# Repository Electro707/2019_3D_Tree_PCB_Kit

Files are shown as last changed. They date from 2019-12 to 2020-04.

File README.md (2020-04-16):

# 2019_3D_Tree_PCB_Kit
A soldering kit of a "3D" Christmas Tree

This repository is archived, as it's a one-time design.
Now files are hosted on Google Drive.

Link to website, in which the Google Drive link can be found:
[Link](https://electro707.com/documentation/PCB/2019_3DChristmasTree/index.php)

I may create a new general reposity for the kit that will be updated as time goes on 
(there also won't be any of the University of New Haven logos on that one).

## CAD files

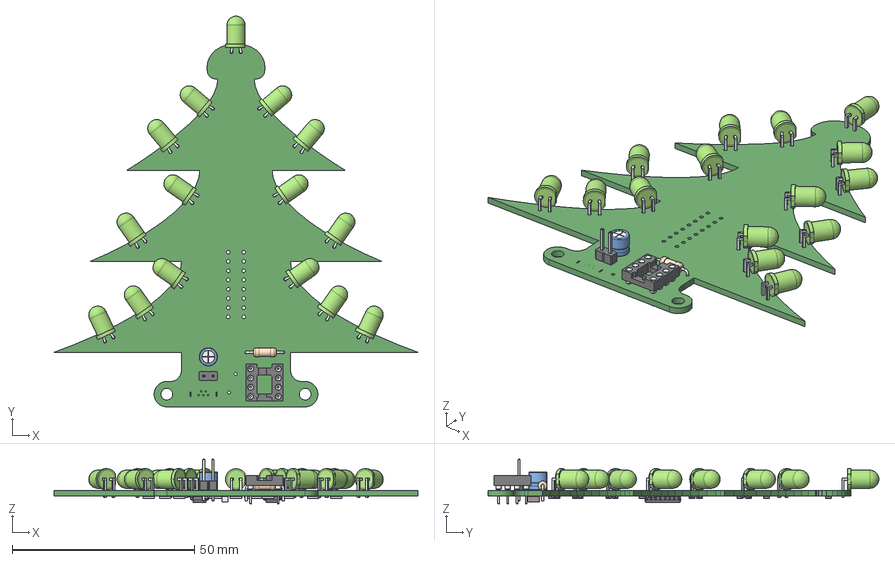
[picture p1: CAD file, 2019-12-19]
CAD - Inventor/Main Tree.step
100.0 x 107.4 x 12.3 mm

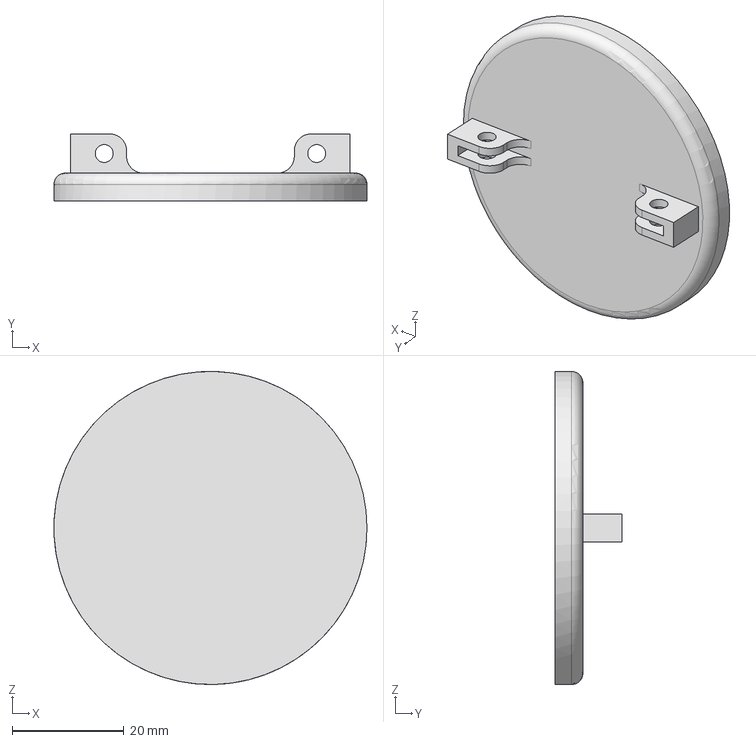
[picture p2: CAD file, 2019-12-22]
Base STEP and STL/Base.stp
56.0 x 12.0 x 56.0 mm

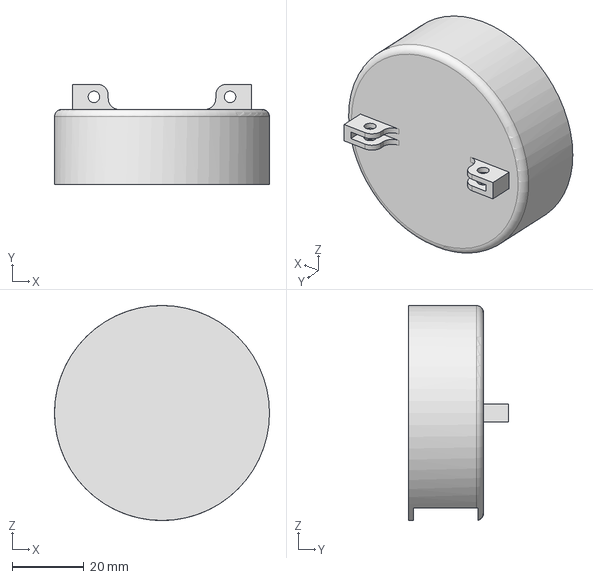
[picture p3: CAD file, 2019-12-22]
Base STEP and STL/Base with 9V Batt.stp
60.0 x 28.0 x 60.0 mm

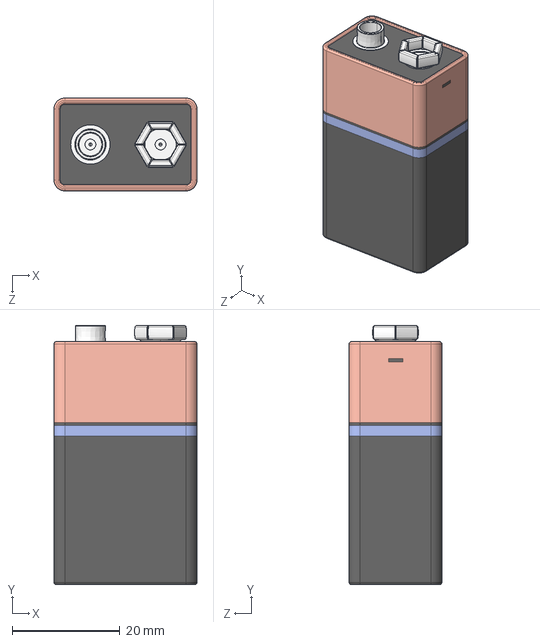
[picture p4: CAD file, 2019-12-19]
CAD - Inventor/9V Battery.STEP
26.5 x 48.0 x 17.2 mm

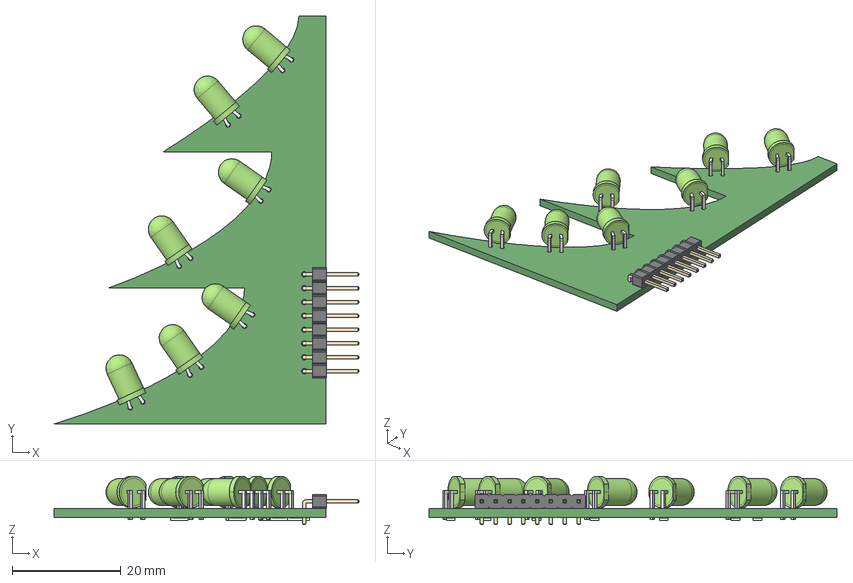
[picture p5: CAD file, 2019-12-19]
CAD - Inventor/Aux Tree.step
56.0 x 75.0 x 8.90 mm

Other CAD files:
CAD - Inventor/Drawings.dwg
Base STEP and STL/Base with 9V Batt.stl
Base STEP and STL/Base.stl
CAD - Inventor/Assembly - Aux Tree.iam
CAD - Inventor/Assembly - Main Tree.iam
CAD - Inventor/Assembly - Whole - 9V base.iam
CAD - Inventor/Assembly - Whole.iam
CAD - Inventor/Assembly - Whole.ipn
CAD - Inventor/Base with 9V Batt.ipt
CAD - Inventor/Base.ipt
CAD - Inventor/DIP-8_W7.62mm.ipt
CAD - Inventor/OldVersions/Assembly - Whole.0033.ipn
CAD - Inventor/OldVersions/Assembly - Whole.0034.iam

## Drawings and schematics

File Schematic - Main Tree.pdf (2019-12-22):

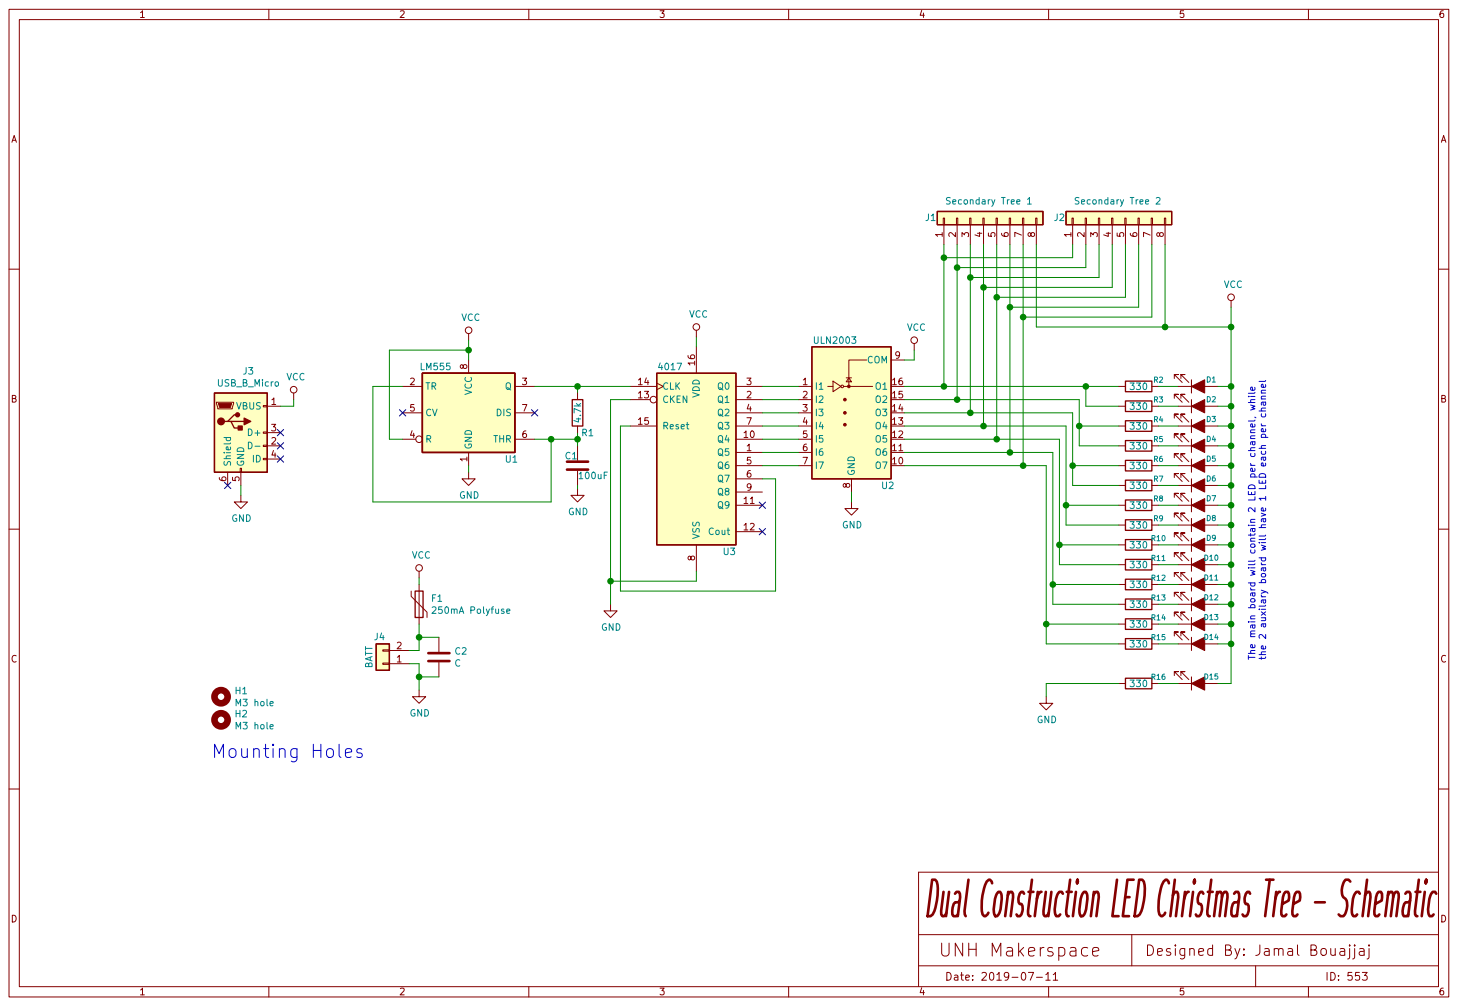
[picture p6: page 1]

H1M3 hole H2M3 hole Mounting Holes

Dual Construction LED Christmas Tree - Schematic

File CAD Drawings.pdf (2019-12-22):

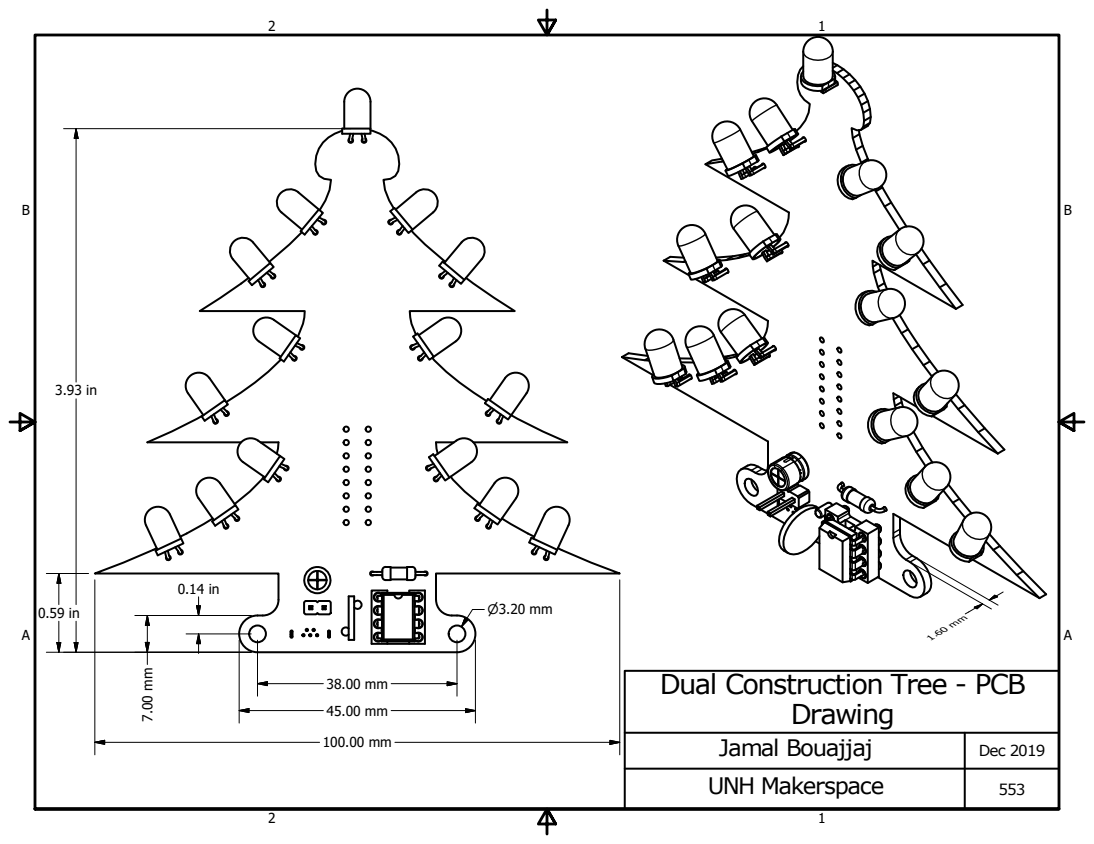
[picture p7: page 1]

Dual Construction Tree - PCB

Jamal Bouajjaj | Dec 2019
UNH Makerspace | 553

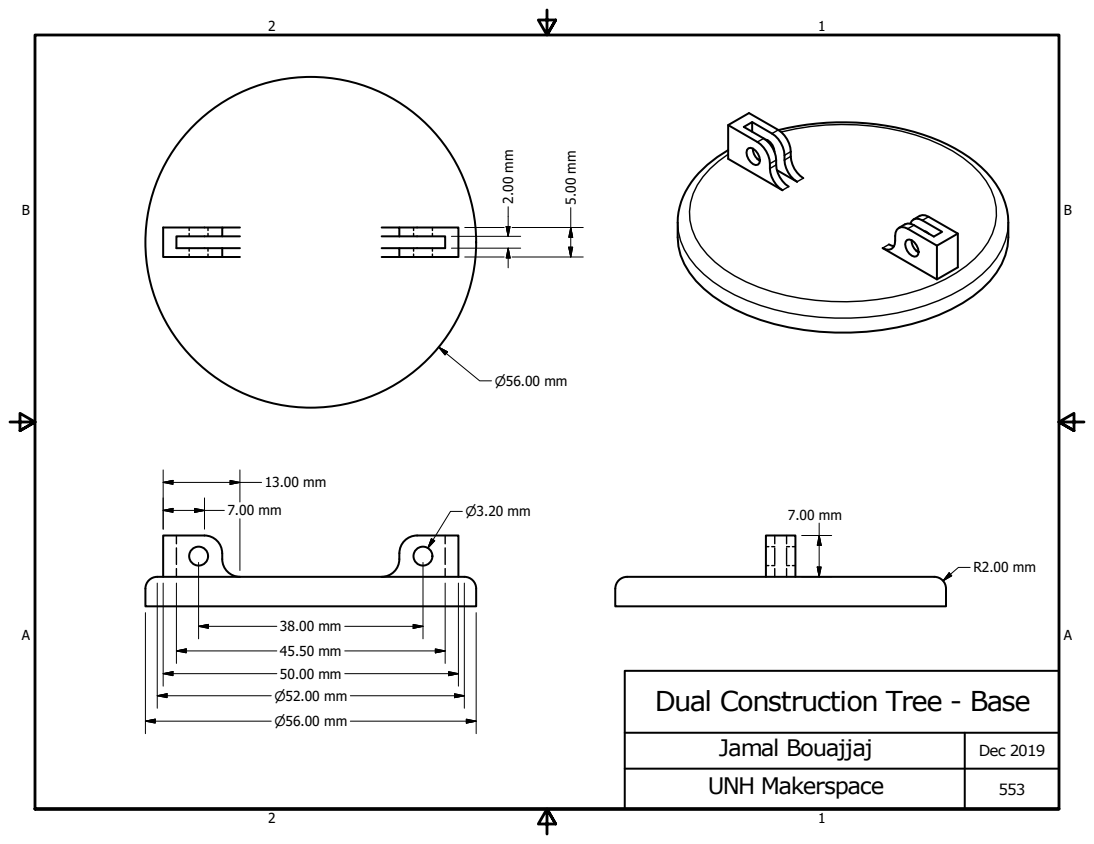
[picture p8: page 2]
Jamal Bouajjaj; Dec 2019

Dual Construction Tree - Base

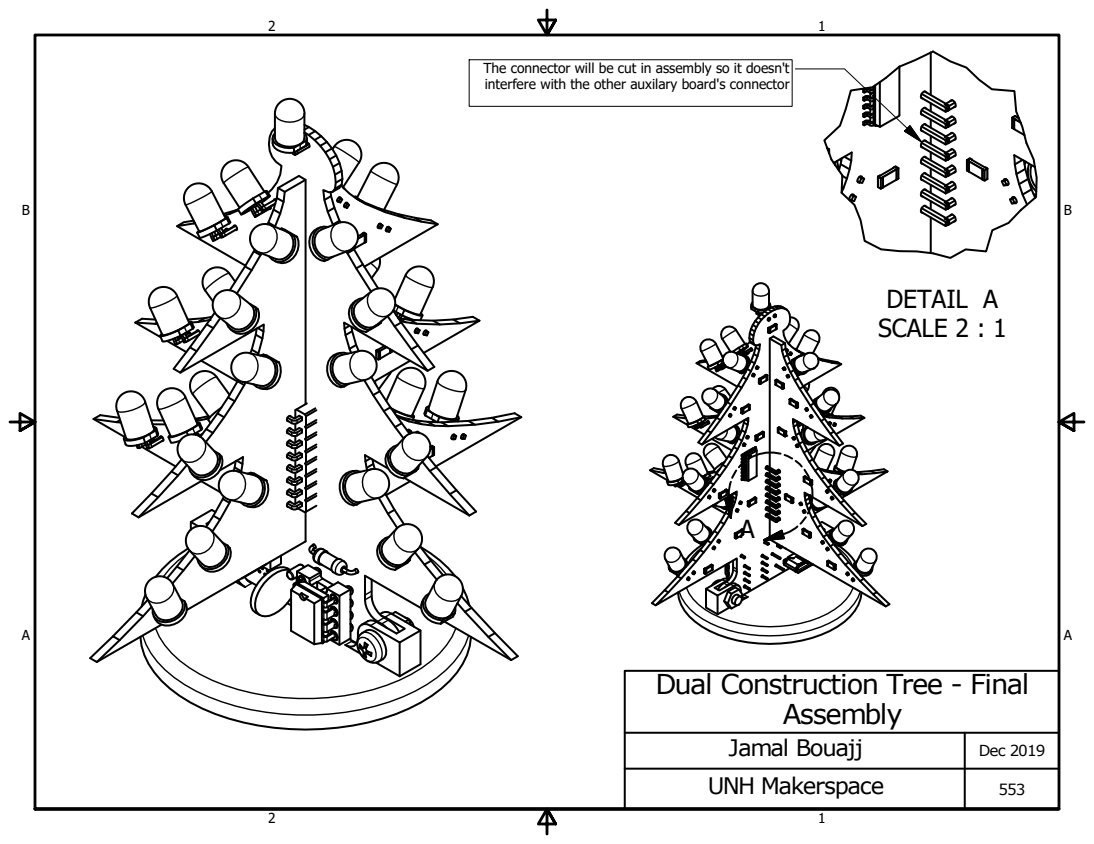
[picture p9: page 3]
DETAIL A SCALE 2 : 1; Jamal Bouajj; Dec 2019

The connector will be cut in assembly so it doesn't
interfere with the other auxilary board's connector

Dual Construction Tree - Final

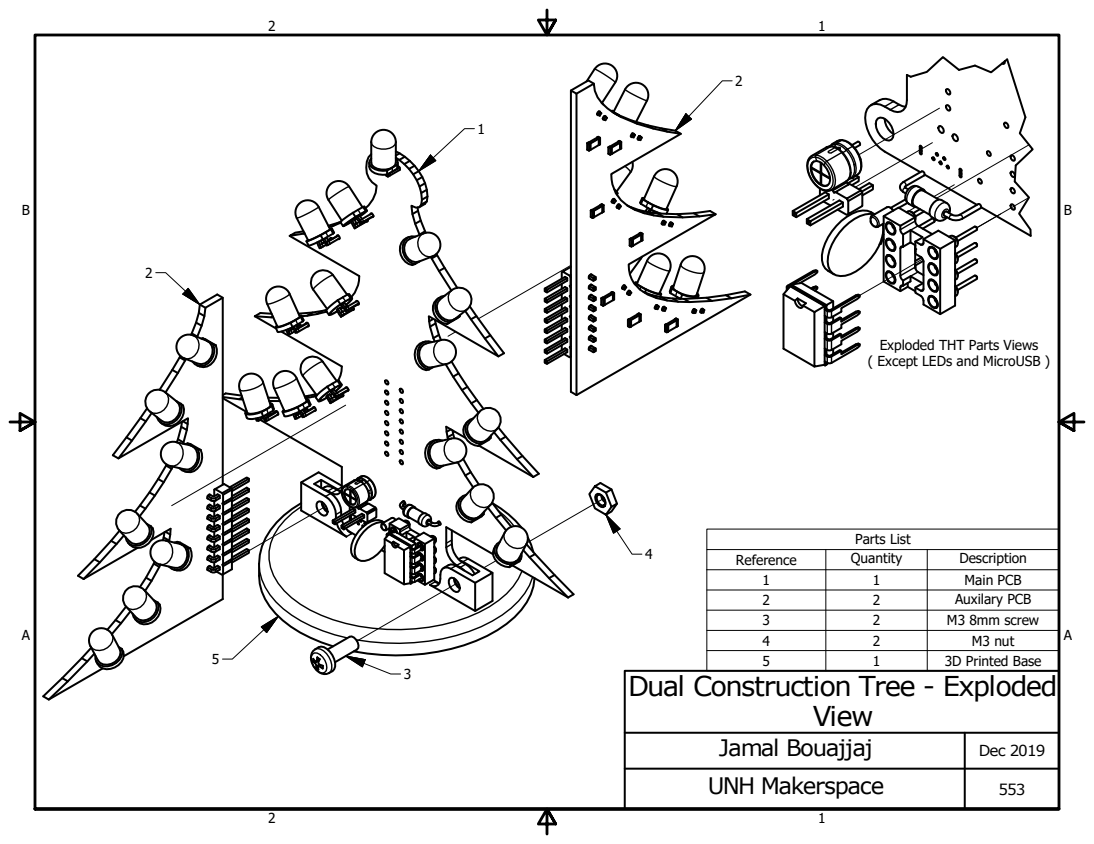
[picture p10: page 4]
Jamal Bouajjaj; Dec 2019; Parts List

Exploded THT Parts Views
( Except LEDs and MicroUSB )

Reference | Quantity | Description
1 | 1 | Main PCB
2 | 2 | Auxilary PCB
3 | 2 | M3 8mm screw
4 | 2 | M3 nut
5 | 1 | 3D Printed Base

Dual Construction Tree - Exploded

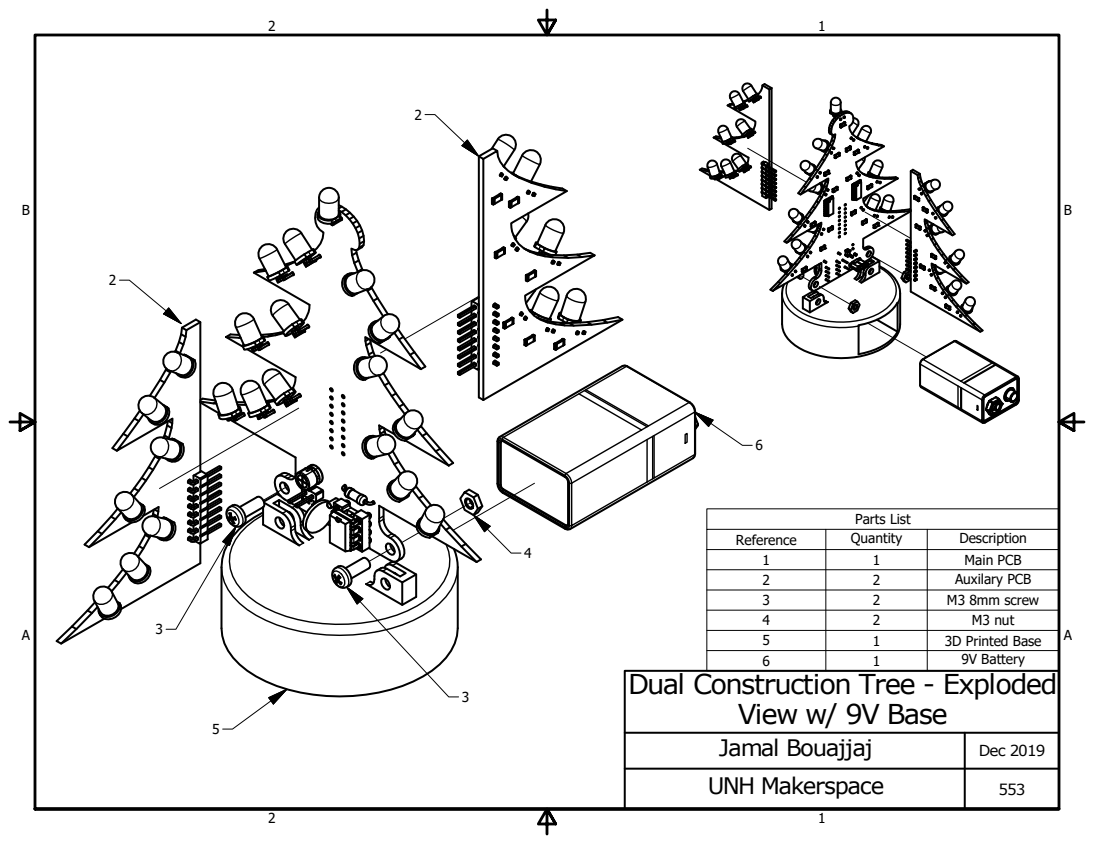
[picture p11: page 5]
View w/ 9V Base; Jamal Bouajjaj; Dec 2019; Parts List

Reference | Quantity | Description
1 | 1 | Main PCB
2 | 2 | Auxilary PCB
3 | 2 | M3 8mm screw
4 | 2 | M3 nut
5 | 1 | 3D Printed Base
6 | 1 | 9V Battery

Dual Construction Tree - Exploded

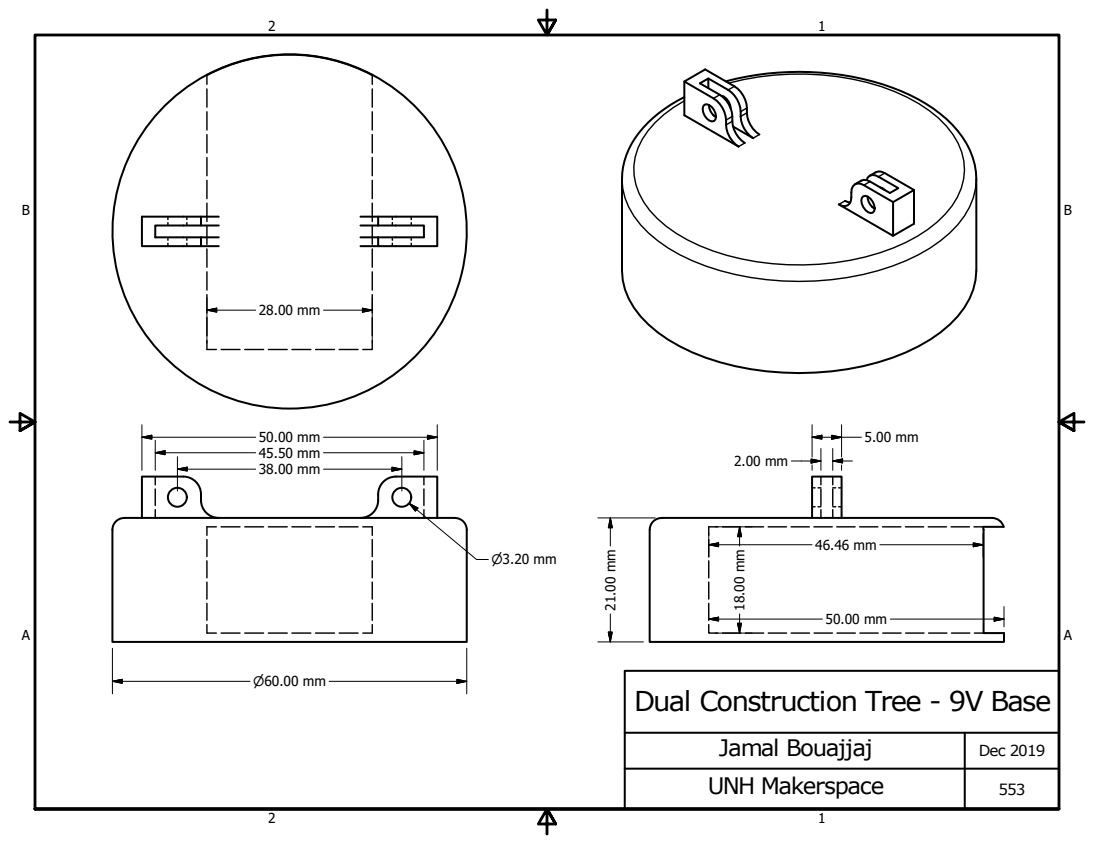
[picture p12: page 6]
Jamal Bouajjaj; Dec 2019

Dual Construction Tree - 9V Base

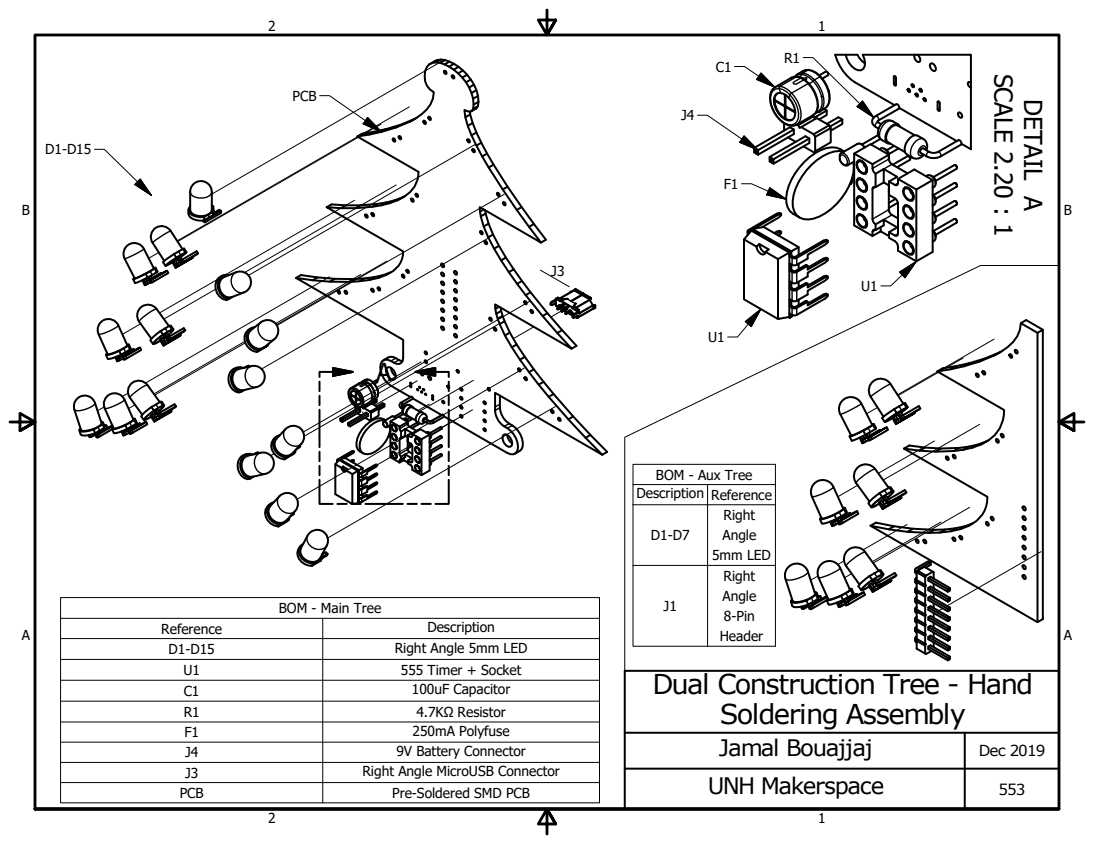
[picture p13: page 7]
Jamal Bouajjaj; Dec 2019

BOM - Aux Tree

Description | Reference
D1-D7 | Right Angle 5mm LED

J1 | Right Angle 8-Pin Header

BOM - Main Tree

Reference | Description
D1-D15 | Right Angle 5mm LED
U1 | 555 Timer + Socket
C1 | 100uF Capacitor
R1 | 4.7K Resistor
F1 | 250mA Polyfuse
J4 | 9V Battery Connector
J3 | Right Angle MicroUSB Connector
PCB | Pre-Soldered SMD PCB

Dual Construction Tree - Hand
Soldering Assembly

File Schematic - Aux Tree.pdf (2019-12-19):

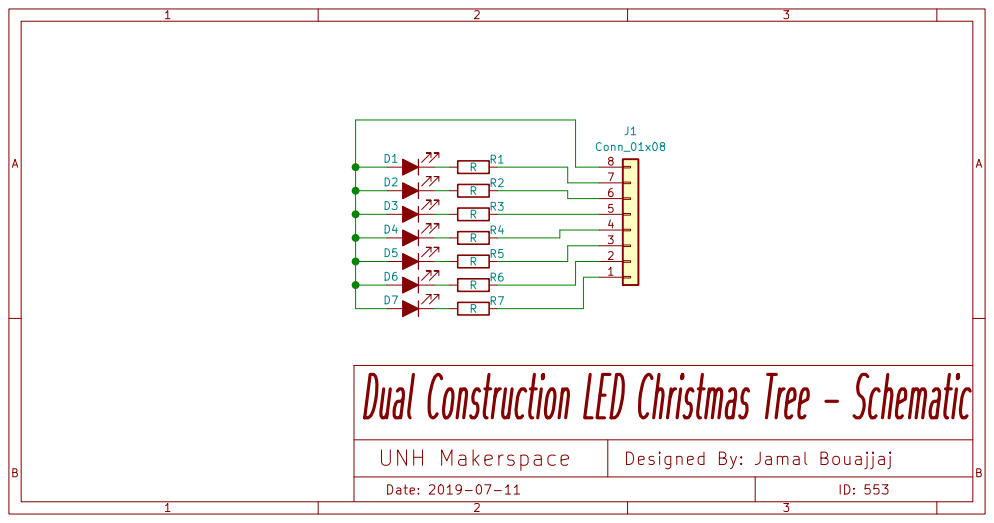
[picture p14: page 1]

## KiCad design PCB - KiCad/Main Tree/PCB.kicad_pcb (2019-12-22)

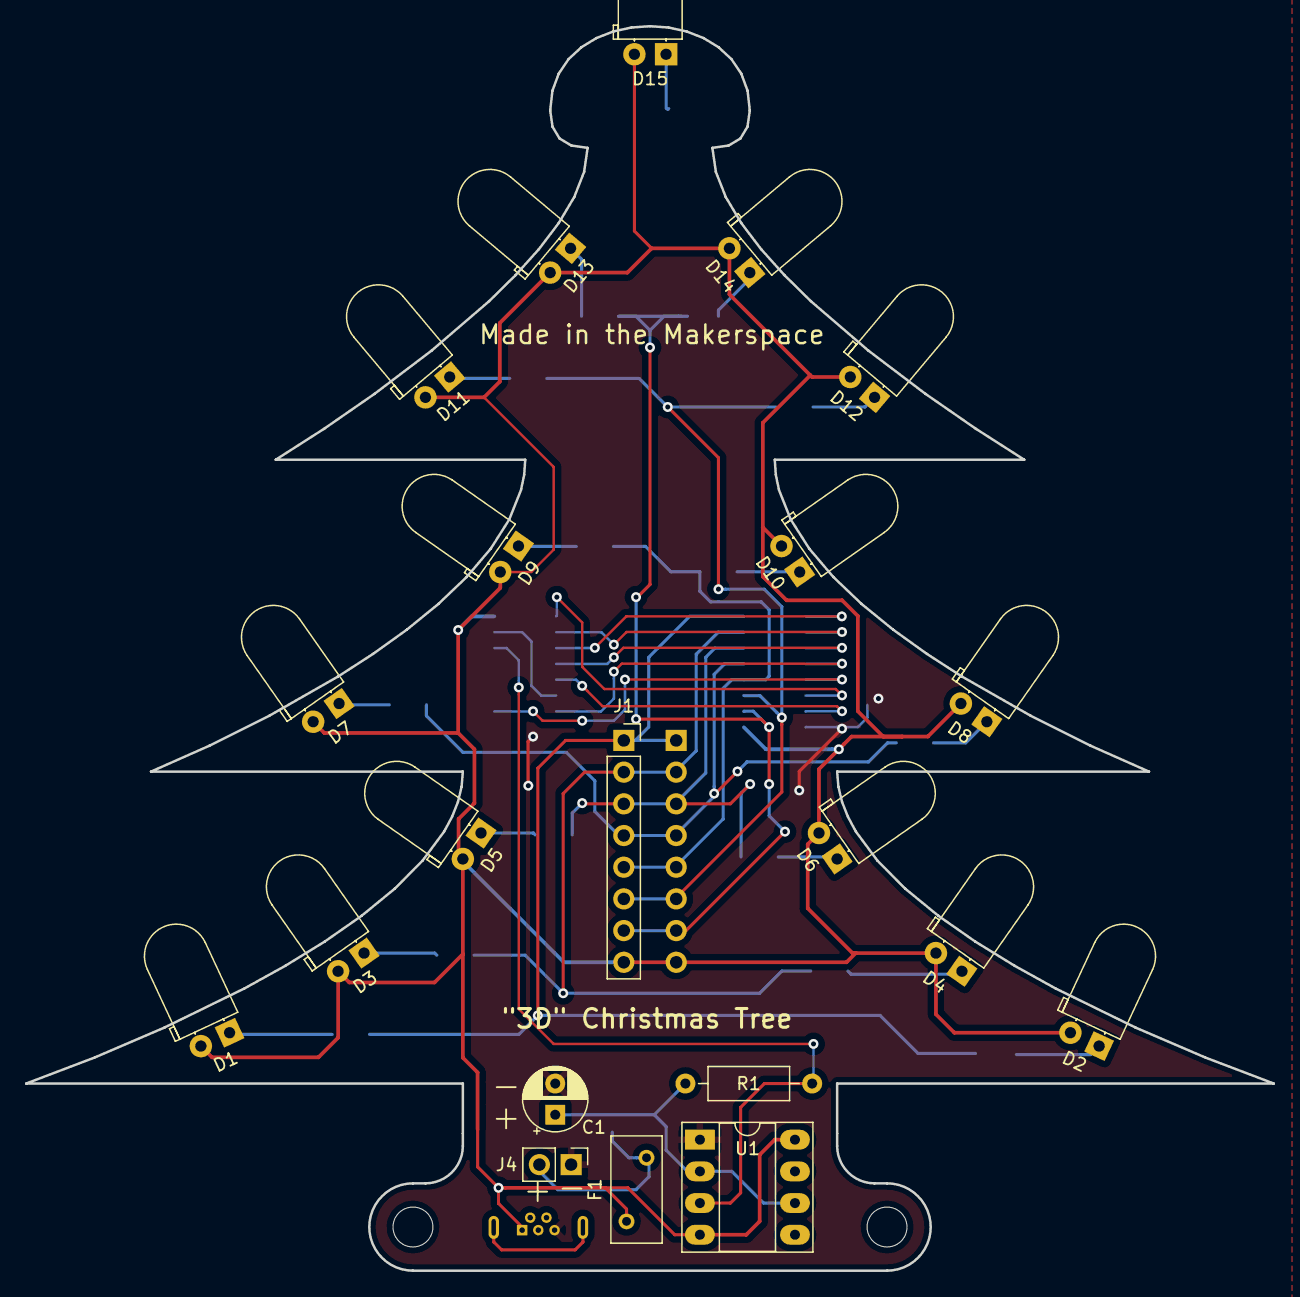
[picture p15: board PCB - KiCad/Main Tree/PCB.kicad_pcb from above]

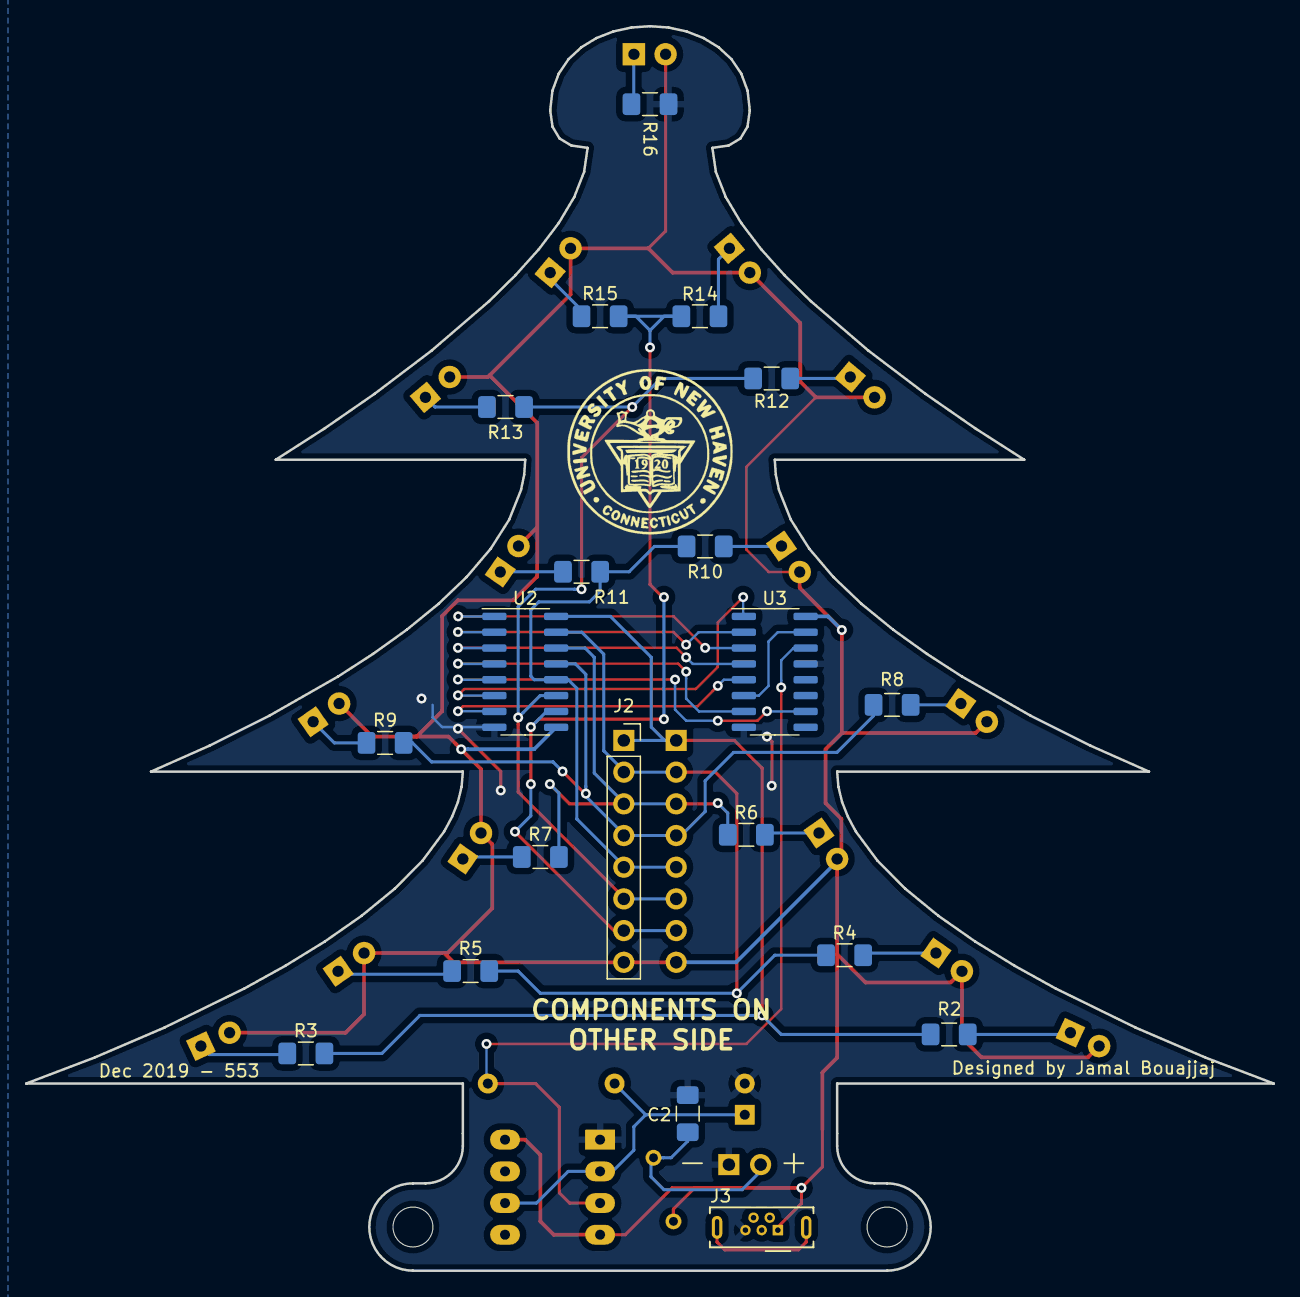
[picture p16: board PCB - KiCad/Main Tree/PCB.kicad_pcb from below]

Board: 2 copper layers, 100.0 x 99.8 mm, 43 parts (20 on the bottom side), 35 nets.

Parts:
C1: C; CP_Radial_D5.0mm_P2.50mm
C2: C; C_1206_3216Metric_Pad1.42x1.75mm_HandSolder
D1, D2, D3, D4, D5, D6, D7, D8, D9, D10, D11, D12, D13, D14, D15: LED_ALT; LED_D5.0mm_Horizontal_O1.27mm_Z3.0mm
F1: Polyfuse; Fuse_BelFuse_0ZRE0005FF_L8.3mm_W3.8mm
H1, H2: M3 hole; MountingHole_3.2mm_M3_DIN965
J1: Secondary Tree 1; PinSocket_1x08_P2.54mm_Vertical
J2: Secondary Tree 2; PinSocket_1x08_P2.54mm_Vertical
J3: USB_B_Micro; USB_Micro-B_Wuerth_614105150721_Vertical
J4: BATT; PinHeader_1x02_P2.54mm_Vertical
R1: R; R_Axial_DIN0207_L6.3mm_D2.5mm_P10.16mm_Horizontal
R2, R3, R4, R5, R6, R7, R8, R9, R10, R11, R12, R13, R14, R15, R16: 330; R_1206_3216Metric_Pad1.42x1.75mm_HandSolder
U1: LM555; DIP-8_W7.62mm_Socket_LongPads
U2: ULN2003; SOIC-16_3.9x9.9mm_P1.27mm
U3: 4017; SOIC-16_3.9x9.9mm_P1.27mm

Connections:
GND: C1.2, C2.2, J3.5, J4.1, R16.2, U1.1, U2.8, U3.8, U3.13
unnamed: C1.1, R1.2, U1.2, U1.6
unnamed: C2.1, F1.2, J4.2
unnamed: D1.1, R2.1
unnamed: D2.1, R3.1
unnamed: D3.1, R4.1
unnamed: D4.1, R5.1
unnamed: D5.1, R6.1
unnamed: D6.1, R7.1
unnamed: D7.1, R8.1
unnamed: D8.1, R9.1
unnamed: D9.1, R10.1
unnamed: D10.1, R11.1
unnamed: D11.1, R12.1
unnamed: D12.1, R13.1
unnamed: D13.1, R14.1
unnamed: D14.1, R15.1
unnamed: D15.1, R16.1
unnamed: J1.1, J2.1, R2.2, R3.2, U2.16
unnamed: J1.2, J2.2, R4.2, R5.2, U2.15
unnamed: J1.3, J2.3, R6.2, R7.2, U2.14
unnamed: J1.4, J2.4, R8.2, R9.2, U2.13
unnamed: J1.5, J2.5, R10.2, R11.2, U2.12
unnamed: J1.6, J2.6, R12.2, R13.2, U2.11
unnamed: J1.7, J2.7, R14.2, R15.2, U2.10
unnamed: R1.1, U1.3, U3.14
unnamed: U2.1, U3.3
unnamed: U2.2, U3.2
unnamed: U2.3, U3.4
unnamed: U2.4, U3.7
unnamed: U2.5, U3.10
unnamed: U2.6, U3.1
unnamed: U2.7, U3.5
unnamed: U3.6, U3.15
VCC: D1.2, D2.2, D3.2, D4.2, D5.2, D6.2, D7.2, D8.2, D9.2, D10.2, D11.2, D12.2, D13.2, D14.2, D15.2, F1.1, J1.8, J2.8, J3.1, U1.4, U1.8, U2.9, U3.16

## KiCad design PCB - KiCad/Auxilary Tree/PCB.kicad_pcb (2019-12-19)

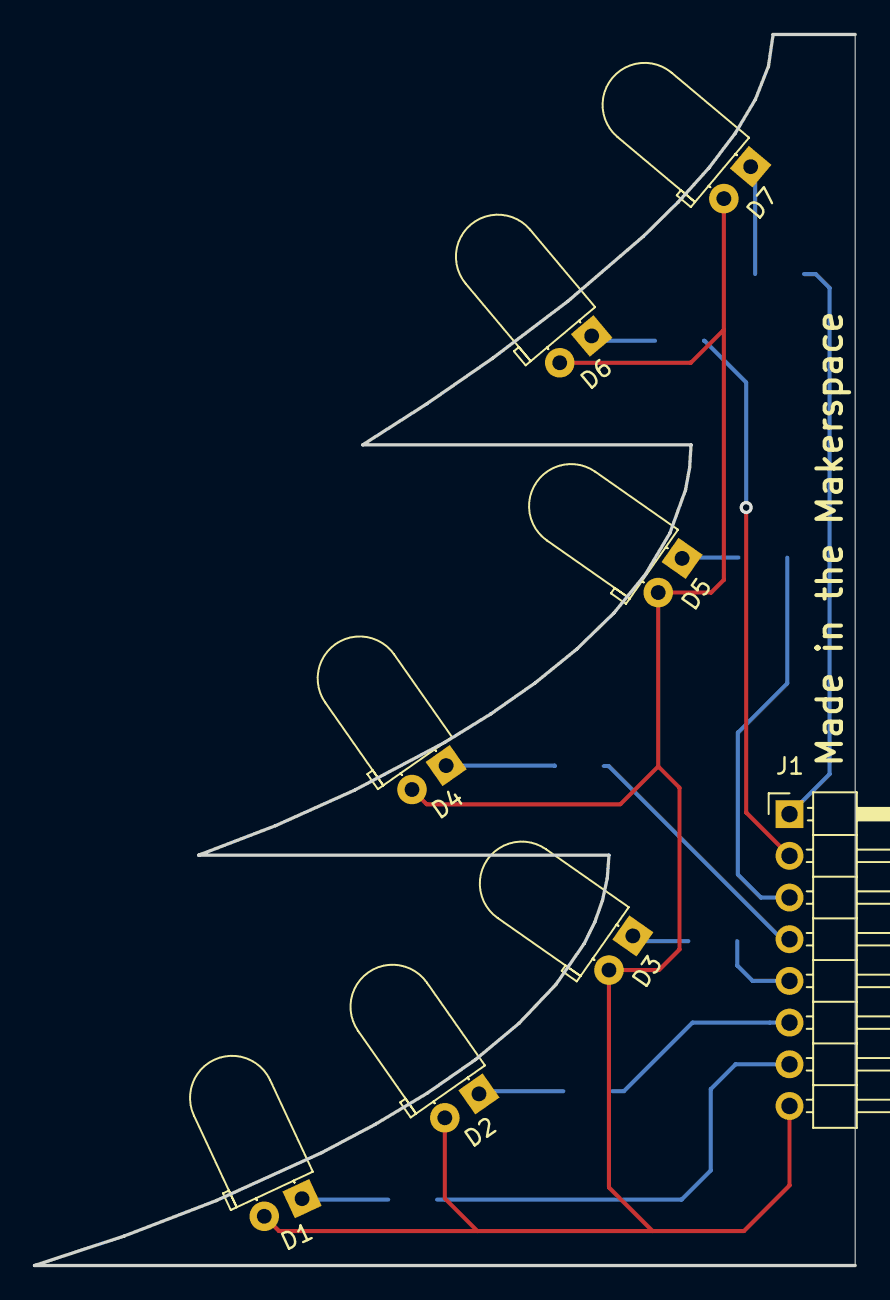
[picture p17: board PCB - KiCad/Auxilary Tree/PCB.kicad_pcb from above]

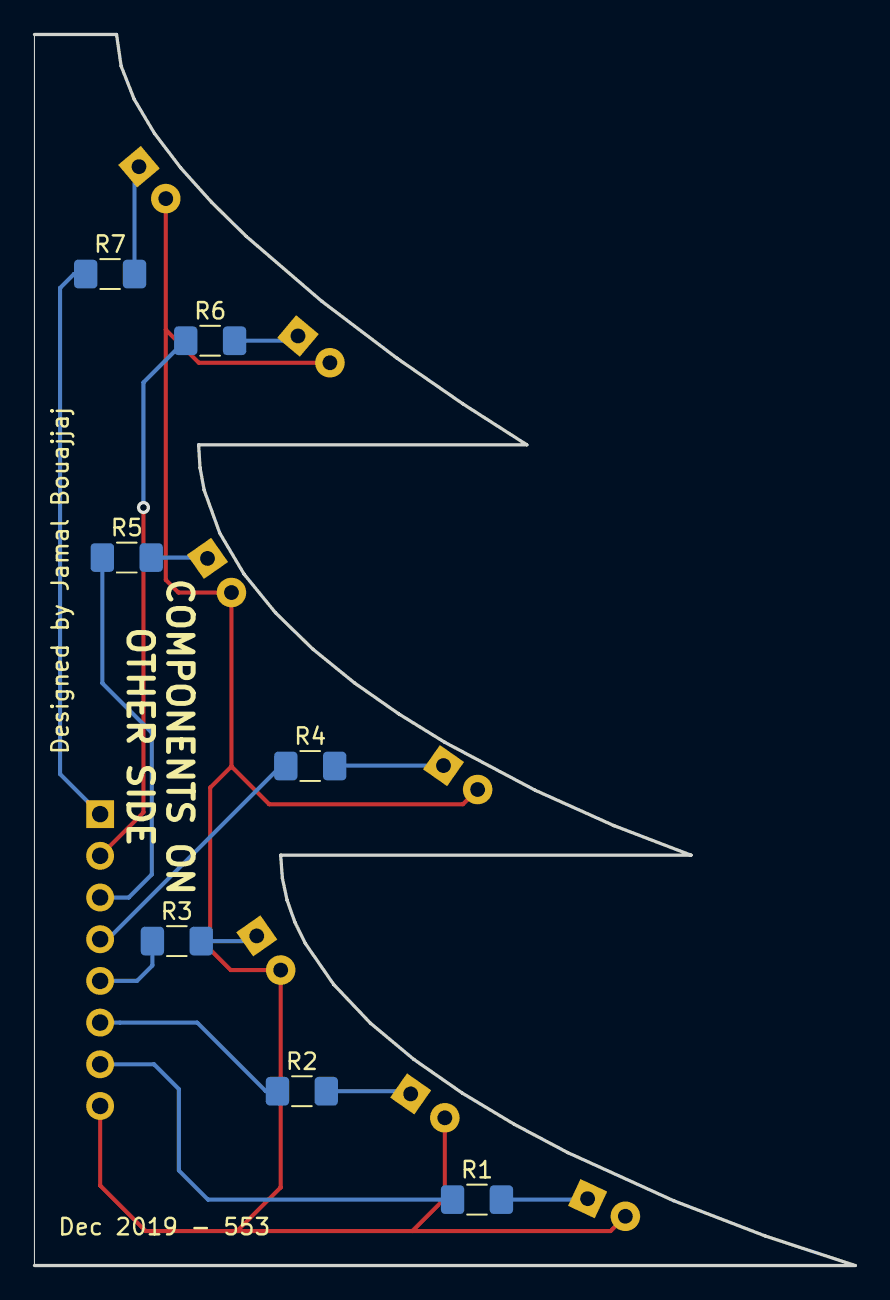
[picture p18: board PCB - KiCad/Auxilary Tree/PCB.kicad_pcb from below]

Board: 2 copper layers, 50.0 x 75.0 mm, 15 parts (7 on the bottom side), 15 nets.

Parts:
D1, D2, D3, D4, D5, D6, D7: LED_ALT; LED_D5.0mm_Horizontal_O1.27mm_Z3.0mm
J1: Conn_01x08; PinHeader_1x08_P2.54mm_Horizontal
R1, R2, R3, R4, R5, R6, R7: R; R_1206_3216Metric_Pad1.42x1.75mm_HandSolder

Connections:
unnamed: D1.1, R1.2
unnamed: D1.2, D2.2, D3.2, D4.2, D5.2, D6.2, D7.2, J1.8
unnamed: D2.1, R2.2
unnamed: D3.1, R3.2
unnamed: D4.1, R4.2
unnamed: D5.1, R5.2
unnamed: D6.1, R6.2
unnamed: D7.1, R7.2
unnamed: J1.1, R7.1
unnamed: J1.2, R6.1
unnamed: J1.3, R5.1
unnamed: J1.4, R4.1
unnamed: J1.5, R3.1
unnamed: J1.6, R2.1
unnamed: J1.7, R1.1
